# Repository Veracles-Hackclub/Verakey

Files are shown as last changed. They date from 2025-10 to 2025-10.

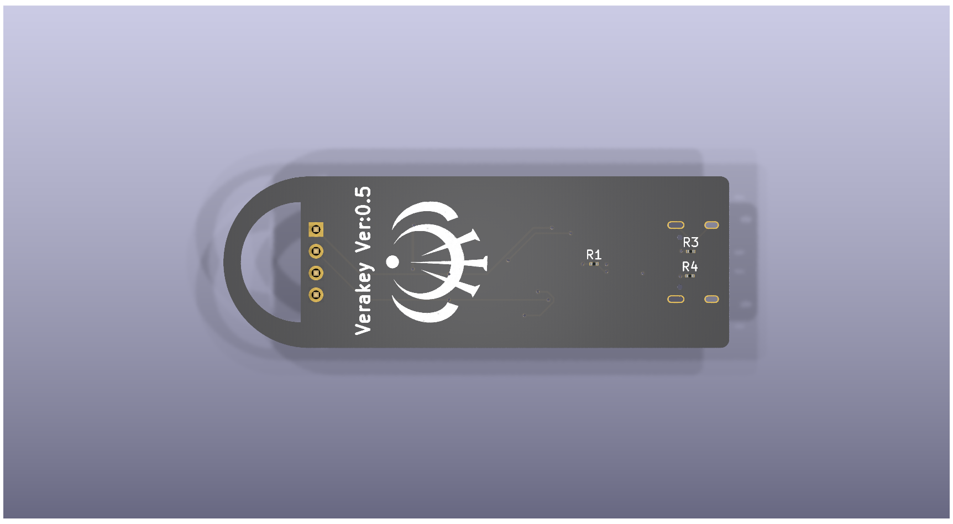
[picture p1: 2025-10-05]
Verakey.png

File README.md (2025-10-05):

# Verakey
A custom Yubikey I'm designing to act as a cool keychain for my backpack! Along with having a keyring for me to mount it to a carabiner, it doesn't have a button, but instead a OLED screen I plan on adding some cute animations to, maybe a frog or something.

Verakey



It uses the STM32L432KBUx with an ATECC608 for maximum security, and will have the following protocol stack
-FIDO2
-U2F
-HOTP
-PIV

for maximal security. I also added a cool silkscreen.

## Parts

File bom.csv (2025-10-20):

Qty | Part Name | Unit Price | Extended | Link
3 | 1uF 0402 Capacitor | $0.26 | $0.78 | https://www.digikey.com/en/products/detail/yageo/CC0402KRX5R8BB105/5195107
1 | 10uF 0603 Capacitor | $0.42 | $0.42 | https://www.digikey.com/en/products/detail/yageo/CC0603MRX5R7BB106/5195229
2 | 1uF 0603 Capacitor | $0.26 | $0.52 | https://www.digikey.com/en/products/detail/yageo/CC0402KRX5R8BB105/5195107
1 | 100nF 0504 Capacitor | $1.52 | $1.52 | https://www.digikey.com/en/products/detail/knowles-novacap/0504X103K500PX/7798547
2 | SK6812MINI LED | N/A | $4.95 | https://www.digikey.com/en/products/detail/adafruit-industries-llc/2686/5804107
1 | 500mA 1206 Fuse | n/a | n/a | n/a
1 | 4-Pin Header 2.54mm | n/a | n/a | n/a
1 | USB-C Receptacle 16-Pin | $2.68 | $2.68 | https://www.digikey.com/en/products/detail/hirose-electric-co-ltd/CX90BW-16P1/22565305
2 | 22Ω 0201 Resistor | n/a | n/a | n/a
2 | 5.1kΩ 0201 Resistor | n/a | n/a | n/a
4 | 4.7kΩ 0402 Resistor | n/a | n/a | n/a
1 | 10kΩ 0603 Resistor | n/a | n/a | n/a
1 | STM32L432KBUx Microcontroller | $4.19 | $4.19 | https://www.digikey.com/en/products/detail/stmicroelectronics/STM32L432KBU6/6132748
1 | ATECC608A-MAHDA Auth Chip | $0.97 | $0.97 | https://www.digikey.com/en/products/detail/microchip-technology/ATECC608A-MAHDA-T/7928114
1 | USBLC6-2SC6 ESD Protection | $0.36 | $0.36 | https://www.digikey.com/en/products/detail/stmicroelectronics/USBLC6-2SC6/1040559
1 | TLV75533PDBV Voltage Regulator | $0.38 | $0.38 | https://www.digikey.com/en/products/detail/texas-instruments/TLV75533PDBVR/9356541
1 | PCB Fabrication | $2.10 | $2.10 | n/a
 |  |  | TOTAL | $30.11

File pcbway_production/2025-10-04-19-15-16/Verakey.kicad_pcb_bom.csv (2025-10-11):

Designator | Quantity | Value | Footprint | Package | MPN | DNP | Mount_Type | Description
C1, C2, C3 | 3 | 1uF | C_0402_1005Metric |  |  |  | smt | capacitor, small US symbol
C4 | 1 | 10uF | C_0603_1608Metric |  |  |  | smt | capacitor, small US symbol
C5, C6 | 2 | 1uF | C_0603_1608Metric |  |  |  | smt | Unpolarized capacitor, small symbol
C7 | 1 | 100nF | C_0504_1310Metric |  |  |  | smt | capacitor, small US symbol
D1, D2 | 2 | SK6812MINI | LED_SK6812MINI_PLCC4_3.5x3.5mm_P1.75mm |  |  |  | smt | RGB LED with integrated controller
F1 | 1 | 500mA | Fuse_1206_3216Metric |  |  |  | smt | Resettable fuse, polymeric positive temperature coefficient, small symbol
J1 | 1 | Conn_01x04_Pin | PinHeader_1x04_P2.54mm_Vertical |  |  |  | tht | Generic connector, single row, 01x04, script generated
J2 | 1 | USB_C_Receptacle_USB2.0_16P | USB_C_Receptacle_Palconn_UTC16-G |  |  |  | smt | USB 2.0-only 16P Type-C Receptacle connector
R1, R2 | 2 | 22 | R_0201_0603Metric |  |  |  | smt | Resistor, small US symbol
R3, R4 | 2 | 5.1k | R_0201_0603Metric |  |  |  | smt | Resistor, small US symbol
R5, R6, R7, R8 | 4 | 4.7k | R_0402_1005Metric |  |  |  | smt | Resistor, small US symbol
R9 | 1 | 10k | R_0603_1608Metric |  |  |  | smt | Resistor, small US symbol
TP1 | 1 | TestPoint_2Pole | PinHeader_1x02_P1.00mm_Vertical |  |  |  | tht | 2-polar test point
U1 | 1 | STM32L432KBUx | QFN-32-1EP_5x5mm_P0.5mm_EP3.45x3.45mm |  |  |  | smt | STMicroelectronics Arm Cortex-M4 MCU, 128KB flash, 64KB RAM, 80 MHz, 1.71-3.6V, 26 GPIO, UFQFPN32
U2 | 1 | ATECC608A-MAHDA | DFN-8-1EP_3x2mm_P0.5mm_EP1.3x1.5mm |  |  |  | smt | Cryptographic Co-Processor with Secure Hardware-based 16 Key Storage, ECDSA and ECDH support, I2C, UDFN-8
U3 | 1 | USBLC6-2SC6 | SOT-23-6 |  |  |  | smt | Very low capacitance ESD protection diode, 2 data-line, SOT-23-6
U4 | 1 | TLV75533PDBV | SOT-23-5 |  |  |  | smt | 500mA Low Dropout Voltage Regulator, Fixed Output 3.3V, SOT-23-5

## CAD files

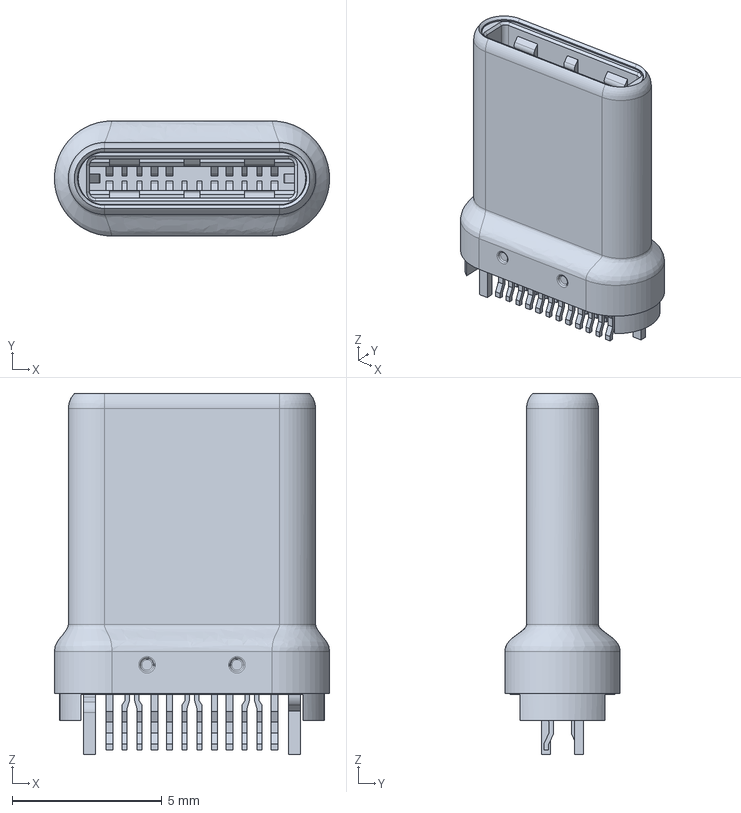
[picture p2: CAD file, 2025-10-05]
1054440001.stp
9.18 x 3.84 x 12.0 mm

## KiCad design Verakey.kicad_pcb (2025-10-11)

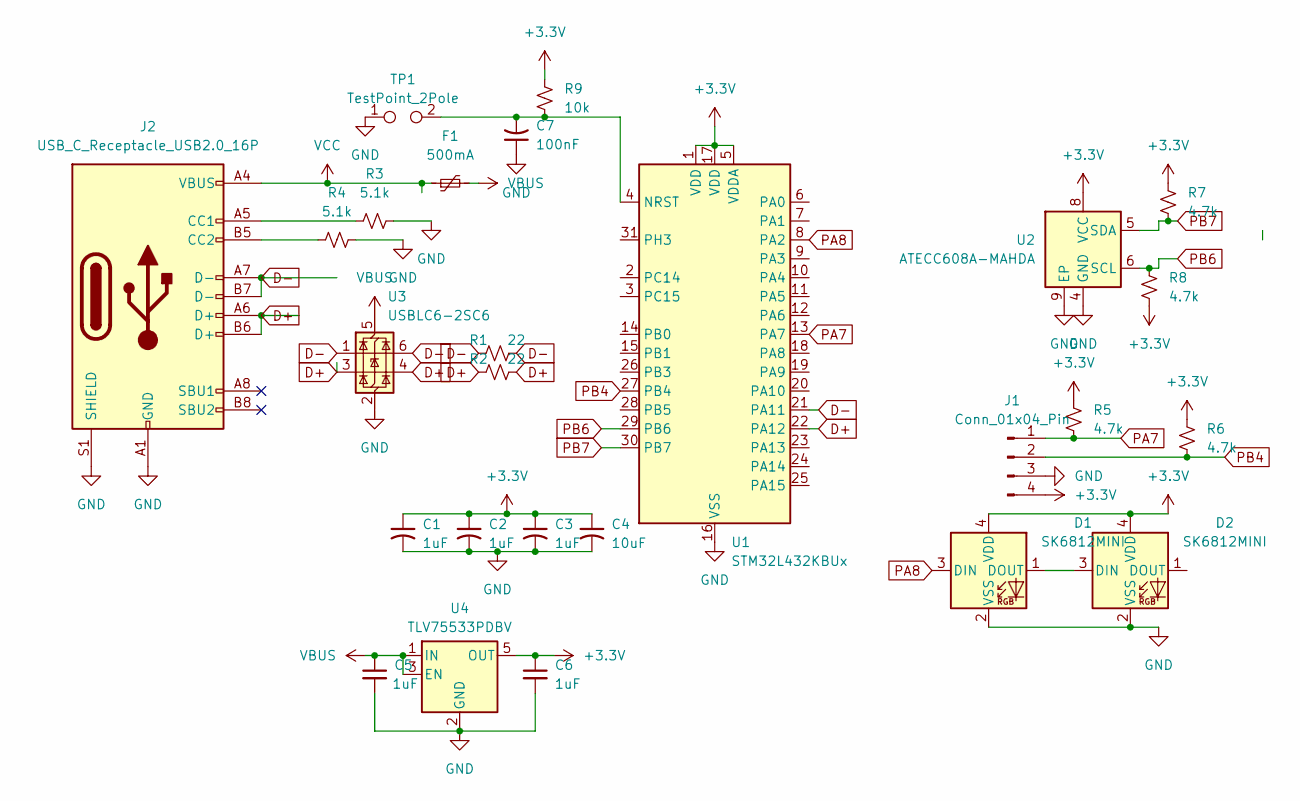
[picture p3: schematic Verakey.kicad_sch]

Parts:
C1, C2, C3: 1uF; C_0402_1005Metric
C4: 10uF; C_0603_1608Metric
C5, C6: 1uF; C_0603_1608Metric
C7: 100nF; C_0504_1310Metric
D1, D2: SK6812MINI; LED_SK6812MINI_PLCC4_3.5x3.5mm_P1.75mm
F1: 500mA; Fuse_1206_3216Metric
J1: Conn_01x04_Pin; PinHeader_1x04_P2.54mm_Vertical
J2: USB_C_Receptacle_USB2.0_16P; USB_C_Receptacle_Palconn_UTC16-G
R1, R2: 22; R_0201_0603Metric
R3, R4: 5.1k; R_0201_0603Metric
R5, R6, R7, R8: 4.7k; R_0402_1005Metric
R9: 10k; R_0603_1608Metric
TP1: TestPoint_2Pole; PinHeader_1x02_P1.00mm_Vertical
U1: STM32L432KBUx; QFN-32-1EP_5x5mm_P0.5mm_EP3.45x3.45mm
U2: ATECC608A-MAHDA; DFN-8-1EP_3x2mm_P0.5mm_EP1.3x1.5mm
U3: USBLC6-2SC6; SOT-23-6
U4: TLV75533PDBV; SOT-23-5

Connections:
+3.3V: C1.1, C2.1, C3.1, C4.1, C6.1, D1.4 (VDD), D2.4 (VDD), J1.4, R5.1, R6.1, R7.1, R8.1, R9.1, U1.1 (VDD), U1.5 (VDDA), U1.17 (VDD), U2.8 (VCC), U4.5 (OUT)
D+: J2.A6 (D+), J2.B6 (D+), R2.1, R2.2, U1.22 (PA12), U3.3 (I/O2), U3.4 (I/O2)
D-: J2.A7 (D-), J2.B7 (D-), R1.1, R1.2, U1.21 (PA11), U3.1 (I/O1), U3.6 (I/O1)
GND: C1.2, C2.2, C3.2, C4.2, C5.2, C6.2, C7.1, D1.2 (VSS), D2.2 (VSS), J1.3, J2.A1 (GND), J2.A12 (GND), J2.B1 (GND), J2.B12 (GND), J2.S1 (SHIELD), R3.2, R4.2, TP1.1, U1.16 (VSS), U1.32 (VSS), U1.33 (VSS), U2.4 (GND), U2.9 (EP), U3.2 (GND), U4.2 (GND)
unnamed: D1.1 (DOUT), D2.3 (DIN)
unnamed: J2.A5 (CC1), R3.1
unnamed: J2.B5 (CC2), R4.1
unnamed: C7.2, R9.2, TP1.2, U1.4 (NRST)
PA7: J1.1, R5.2, U1.13 (PA7)
PA8: D1.3 (DIN), U1.8 (PA2)
PB4: J1.2, R6.2, U1.27 (PB4)
PB6: R8.2, U1.29 (PB6), U2.6 (SCL)
PB7: R7.2, U1.30 (PB7), U2.5 (SDA)
VBUS: C5.1, F1.2, U3.5 (VBUS), U4.1 (IN), U4.3 (EN)
VCC: F1.1, J2.A4 (VBUS), J2.A9 (VBUS), J2.B4 (VBUS), J2.B9 (VBUS)

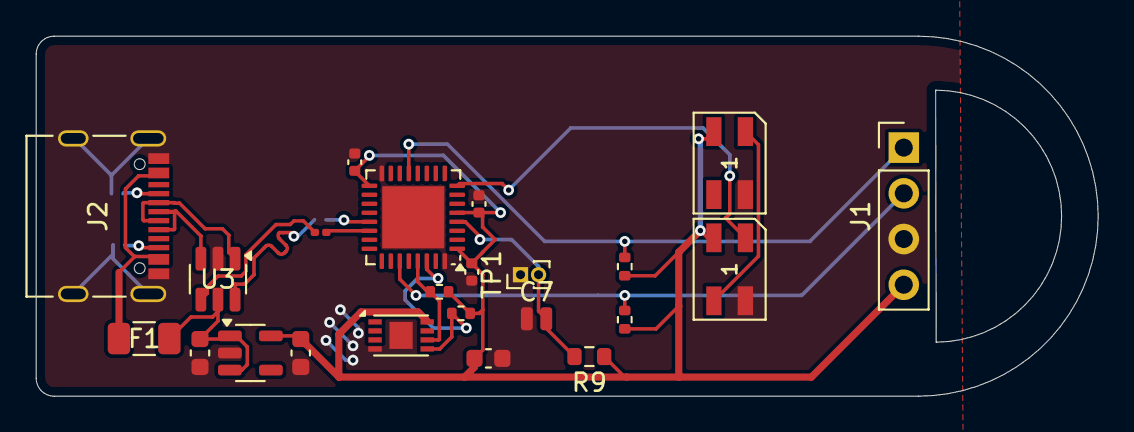
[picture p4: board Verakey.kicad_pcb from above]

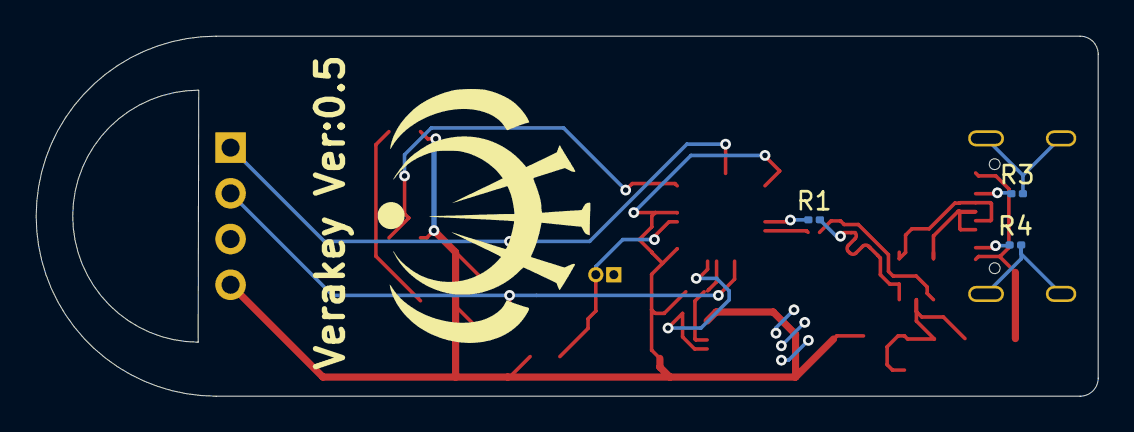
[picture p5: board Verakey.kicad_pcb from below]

Board: 2 copper layers, 59.0 x 20.0 mm, 26 parts (3 on the bottom side), 15 nets.

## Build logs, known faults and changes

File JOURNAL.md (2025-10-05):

<!--
  ===================    !!READ THIS NOTICE!!   ====================
  DO NOT edit this file manually. Your changes WILL BE OVERWRITTEN!
  This journal is auto generated and updated by Hack Club Blueprint.
  To edit this file, please edit your journal entries on Blueprint.
  ==================================================================
-->

This is my journal of the design and building process of **VeraKey**.  
You can view this journal in more detail on **Hack Club Blueprint** [here](https://blueprint.hackclub.com/projects/91).

## 10/4/2025 2 AM - Planning and prep  

I started by spending a few hours exploring potential options, protocols, and security solutions! This took a bit, and I ended up going down a cryptography rabbit hole exploring all of the abusrdly cool options available. In the end I decided to go for a simple design, using a USB-C plug for simplicity, and avoiding the fingerprint sensor, because the cheapest one I can find is 20$ and I need to trim the fat off of these so I can order a few for testing, in case I accidentally brick it in firmware development.



## 10/4/2025 4 AM - Schematics!!  

I started off by creating the main power system, including a polyfuse, USB-C connector, and a ESD protection circuit (can never be too careful, esp with security) I also added a security module and the main STM-32 chip, there's a spare I2C pair I have on this, so I might take advantage of the overkill amount of memory to add an LCD screen to this, for a fun twist!



## 10/4/2025 5 AM - PCB PAIN  

I got the original pcb routed, I had a few issues but I ended up adding a SSD1306 Oled and 2 neopixels for fun! It's a mess rn but DRC is saying yes and frankly that's good enough for me. I honestly might redesign it around 4 layers, because it is really reLLY BOTHERING ME.


## 10/5/2025 12:40 AM - REDESIGN  

I was hating how the current design looked, so I ended up rebuilding it, as well as adding pull up resistors to both I2C lanes, swapping the USP-C plug to a receptacle for more flexibility, and adding a more defined power lane. I also am going to be adding some silkscreen art to the back, and a few other fun things.

I also took this time to perform a comprehensive DRC check,  which took a few hours as I tweaked tolerances and minumum design rules to find the best balance between smart design practice and efficiency. Ultimately I think I did a good job at this, and have only a few parts I actually need to worry about design wise.

I also resized it to fit the OLED screen more effectively, and did a few last rewords of smaller aspects like the secure element (swapped to a smaller footprint) and the connector (found one that was like 10 cents cheaper and a bit smaller.



## 10/5/2025 12:46 AM - DONE  



I figured the design could look really cool with a keychain so I added that, I also populated the model with 3d parts and, with the exception of the neopixel, the secure element, and the USB C connector, have gotten everything ready to be fabricated! I'll add some silkscreen art before I send it out tho :3
